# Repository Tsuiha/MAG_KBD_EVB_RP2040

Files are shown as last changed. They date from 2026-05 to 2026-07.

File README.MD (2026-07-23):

# vial-qmkとRP2040で作る磁気キーボード

rp2040とmuxを使用して作る磁気キーボード用の設計情報です。
簡単なguideにpdfも入れています。

firmwareはvial-qmkのforkです。
[firmware](https://github.com/Tsuiha/vial-qmk/tree/he/keyboards/0_he_rp2040/mag_kbd_evb)

[software](https://tsuiha.github.io/qmagk_configlator/)

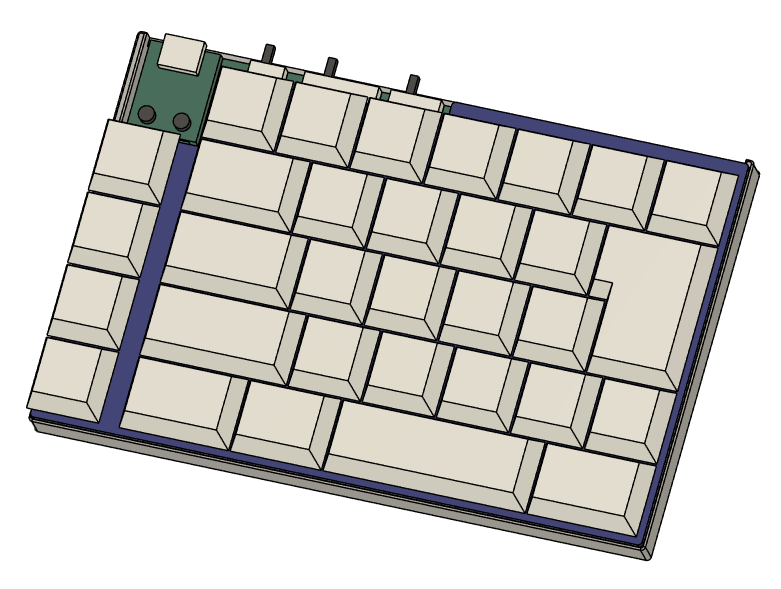
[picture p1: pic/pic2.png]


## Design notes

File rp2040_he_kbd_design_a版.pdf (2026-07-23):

## ○はじめに

## ○事前準備

## ○必要な設定

## ○ホールセンサの接続モード

## ○磁気設定ソフトウェア

quantum\keyboard.c, main.cファイルを一部変更する必要があります。 普段使用しているvial-qmkをコピペしkeyboard.cファイルを置き換えたvial-qmk-heプロジェクトを作成し ます。
https://github.com/Tsuiha/vial-qmk/blob/he/
通常のvial-qmkよりも応答性が改善しております。

config.hファイルを編集し使用するピンやパラメータの設定を行います。 kleで作成したvial用jsonファイルからレイアウト関連ファイルをツールを使い生成します。 その他vial-qmkと同様に設定します。

config.hで3パターンの接続モードから一つを有効化します。 #define DIRECT_ADC_MODE
#define DIRECT_MUX_MODE

#define CHAIN_MUX_MODE

磁気関連のラピトリやsocd, キャリブレーションは専用のソフトウェアを使用し行うことができます。 https://tsuiha.github.io/qmagk_configlator/
キーマップの設定はvialを使用します。

RP2040ZEROで作る！磁気キーボードを元にしたvial-qmkとrp2040を使用して磁気キーボードを設計 参考資料になります。

qmk firmwareでは何も知らない状態からkeyboard.jsonとキーマップを作成して基板を配線するだけ で自作キーボードを設計することができます。

磁気キーボードも同様に設計を行うことができます。そのための設定箇所等についてのメモになりま す。

qmkでの自作キーボード設計、ホールセンサやマルチプレクサの動作や制御について軽く調べておくこ とでスムーズに設計することができます。

またqmk firmwareとrp2040で製作する以上、ポーリングレートがスキャンレートでデッドゾーンの精度 が低遅延なハイスペック機は作れません。

# VIAL-QMKとRP2040で作る！ 磁気キーボード設計

### ○DIRECT_ADC_MODE

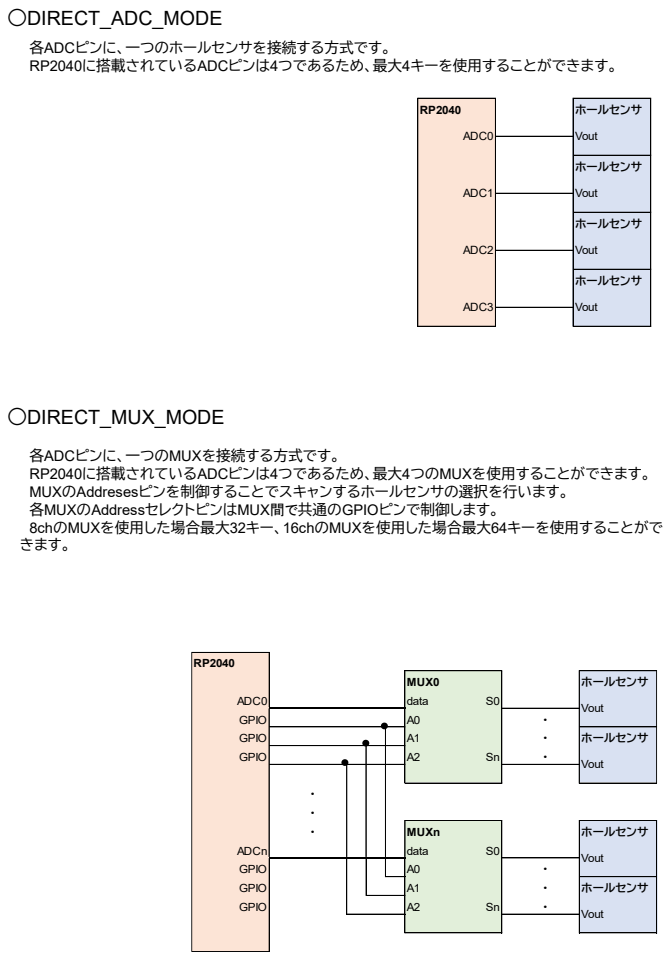
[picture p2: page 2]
○DIRECT_MUX_MODE; 各ADCピンに、一つのMUXを接続する方式です。 RP2040に搭載されているADCピンは4つであるため、最大4つのMUXを使用することができます。 MUXのAddresesピンを制御することでスキャンするホールセンサの選択を行います。 各MUXのAddressセレクトピンはMUX間で共通のGPIOピンで制御します。 8chのMUXを使用した場合最大32キー、16chのMUXを使用した場合最大64キーを使用することがで きます。; 各ADCピンに、一つのホールセンサを接続する方式です。 RP2040に搭載されているADCピンは4つであるため、最大4キーを使用することができます。; ホールセンサ; ADC3; Vout; ADC0; ADC1; ADC2; MUX0; data; GPIO; MUXn; ADCn

### ○CHAIN_MUX_MODE

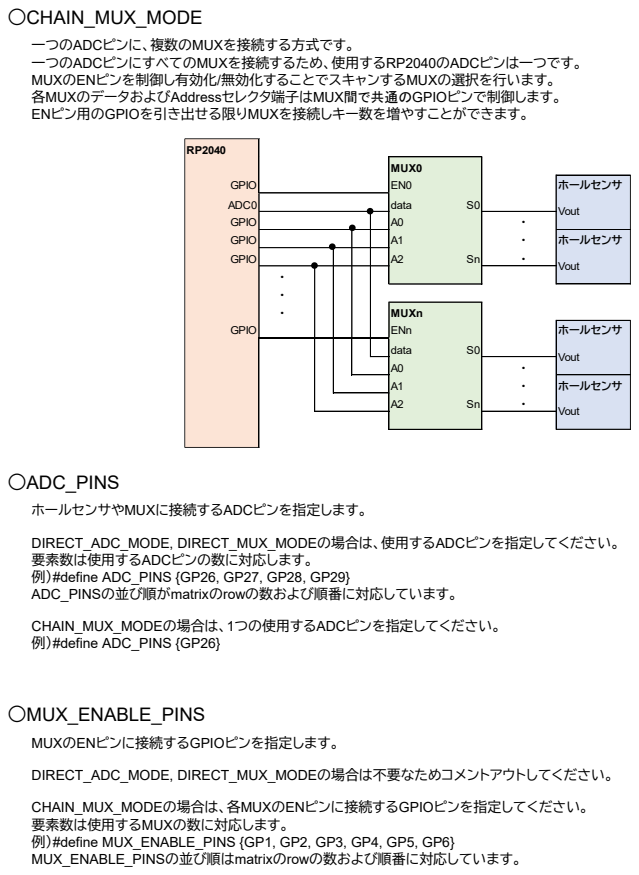
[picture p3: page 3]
○ADC_PINS; ○MUX_ENABLE_PINS; MUXのENピンに接続するGPIOピンを指定します。; DIRECT_ADC_MODE, DIRECT_MUX_MODEの場合は不要なためコメントアウトしてください。; CHAIN_MUX_MODEの場合は、各MUXのENピンに接続するGPIOピンを指定してください。 要素数は使用するMUXの数に対応します。 例）#define MUX_ENABLE_PINS {GP1, GP2, GP3, GP4, GP5, GP6} MUX_ENABLE_PINSの並び順はmatrixのrowの数および順番に対応しています。; ホールセンサやMUXに接続するADCピンを指定します。; DIRECT_ADC_MODE, DIRECT_MUX_MODEの場合は、使用するADCピンを指定してください。 要素数は使用するADCピンの数に対応します。 例）#define ADC_PINS {GP26, GP27, GP28, GP29} ADC_PINSの並び順がmatrixのrowの数および順番に対応しています。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

### ○MUX_CH_ORDER

### ○MUX_SELECT_PINS

### ○MATRIX_ROWS

### ○MATRIX_COLS

DIRECT_ADC_MODE, DIRECT_MUX_MODEの場合、使用するADCピンの数と対応します。 CHAIN_MUX_MODEの場合は、使用するMUXの数と対応します。

DIRECT_ADC_MODEの場合、1になります。
DIRECT_MUX_MODE, CHAIN_MUX_MODEの場合は、使用するMUXのch数と対応します。

MUXのAddressセレクトピンに接続するGPIOピンを指定します。

DIRECT_ADC_MODEの場合は不要なためコメントアウトしてください。

DIRECT_MUX_MODE, CHAIN_MUX_MODEの場合は、セレクタピンに接続するGPIOピンを指定して ください。
要素数は使用するMUXのch数の2進数の桁数に対応します。
例）#define MUX_SELECT_PINS {GP1, GP2, GP3}
MUX_SELECT_PINSの並び順は左側がLSB, 右側がMSBに対応しています。

MUXの使用するchを指定します。

DIRECT_ADC_MODEの場合は不要なためコメントアウトしてください。

DIRECT_MUX_MODE, CHAIN_MUX_MODEの場合は、スキャンする必要のあるchを指定してくださ い。
どのMUXでも使用していないchがある場合、指定せず省いてください。
例）#define MUX_CH_ORDER {0, 1, 2, 3, 4, 5, 6, 7} MUX_CH_ORDERの並び順はmatrixのcolの数および順番に対応しています。

## ○PCBキャリブレーション設定

## ○スイッチキャリブレーション設定

## ○感度オフセット設定

本機では入力感度の調整にsp5tスライドスイッチを使用しており、切り替えることで5段階のキー感度を 利用することができます。
使用するスライドスイッチの各接点に接続するGPIOピンを指定してください。
例）#define SENSI_OFFSET_PINS {GP1, GP2, GP3, GP4, GP5} 要素数は使用するスライドスイッチの接点数に対応します。

各感度ステージでの感度オフセット量をum単位で設定することができます。 例）#define DEF_OFFSET_PONT {0, 50, 100, 200, 500}

＊設定ソフトをリリースしたため、ソフトウェア上で感度ステージを切り替えられるようになりました。 また、vialのユーザーマクロにもsensi offset切り替えキーを作成しております。 スライドスイッチのハードウェア実装はoptionになります。

本機ではキー入力とスイッチキャリブレーションの動作モード切り替えにspdtスライドスイッチを使用し ています。

スライドスイッチのスイッチキャリブレーションモード側接点に接続するGPIOピンを指定してください。 例）#define SW_CAL_PIN GP1

＊設定ソフトをリリースしたため、ソフトウェア上でキャリブレーションを実行できるようになりました。 スライドスイッチのハードウェア実装はoptionになります。

本機ではPCBキャリブレーション用のスイッチとしてタクトスイッチを使用しており、押した状態で起動 するとPCBキャリブレーションが実施されるようになっています。 PCBキャリブレーション用のスイッチに接続するGPIOピンを指定してください。
例）#define PCB_CAL_PIN GP1

ホールセンサの磁束密度ゼロ点出力を取得するものです。 使用するホールセンサに合わせた初期値を設定してしまい、PCBキャリブレーション機能をオミットして も使用に問題はありません
（例えばDRV5055であれば2048を、DRV5056であれば744を固定値として設定してしまう） 例）#define DEF_REF_ADC_VAL 2048

＊設定ソフトをリリースしたため、ソフトウェア上でキャリブレーションを実行できるようになりました。 スライドスイッチのハードウェア実装はoptionになります。

### ○SOCD設定

## ○ゲーミングキー設定

## ○スイッチストローク

### ○KLE to LAYOUT

使用するスイッチのストロークを指定してください。
#define DEF_STROKE 3400

本機の使用ではスイッチストロークの異なるスイッチを使用した場合、感度のみ変化します。 設定ストローク ： 設定感度 ＝ 実ストローク ： 実感度

＊設定ソフトをリリースしたため、ソフトウェア上で設定いただけます。

vial.jsonを生成する際にkleで作成したjsonファイルをもとに作成していると思います。 付属のpywアプリを使用し、kleで作成したjsonファイルから関連layoutファイルをすべて生成することがで きます。
https://github.com/Tsuiha/MAG_KBD_EVB_RP2040/blob/main/pyw/kle_to_layout/kle_multi_layout_to ol.pyw

使用するにはpythonのインストールとpathを通す作業が必要です。

＊設定ソフトをリリースしたため、任意のキーのラピトリ, SOCDを設定いただけます。

本機ではWASDキーに付与するSOCD機能を2つのモードから選択することができます。 SOCDモードの切り替えにsp2tスライドスイッチを使用しています。各端子に接続するGPIOピンを指定 する必要があります。
例）#define SOCD_PINS {GP6, GP7}
SOCD_PINSの並び順は左からOFF, ONに対応しています。 SOCD切り替えにスライドスイッチを使用しない場合はコメントアウトしてください。

＊設定ソフトをリリースしたため、ソフトウェア上でオンオフを切り替えられるようになりました。 また、vialのユーザーマクロにもsocd mode切り替えキーを作成しております。 スライドスイッチのハードウェア実装は になります。

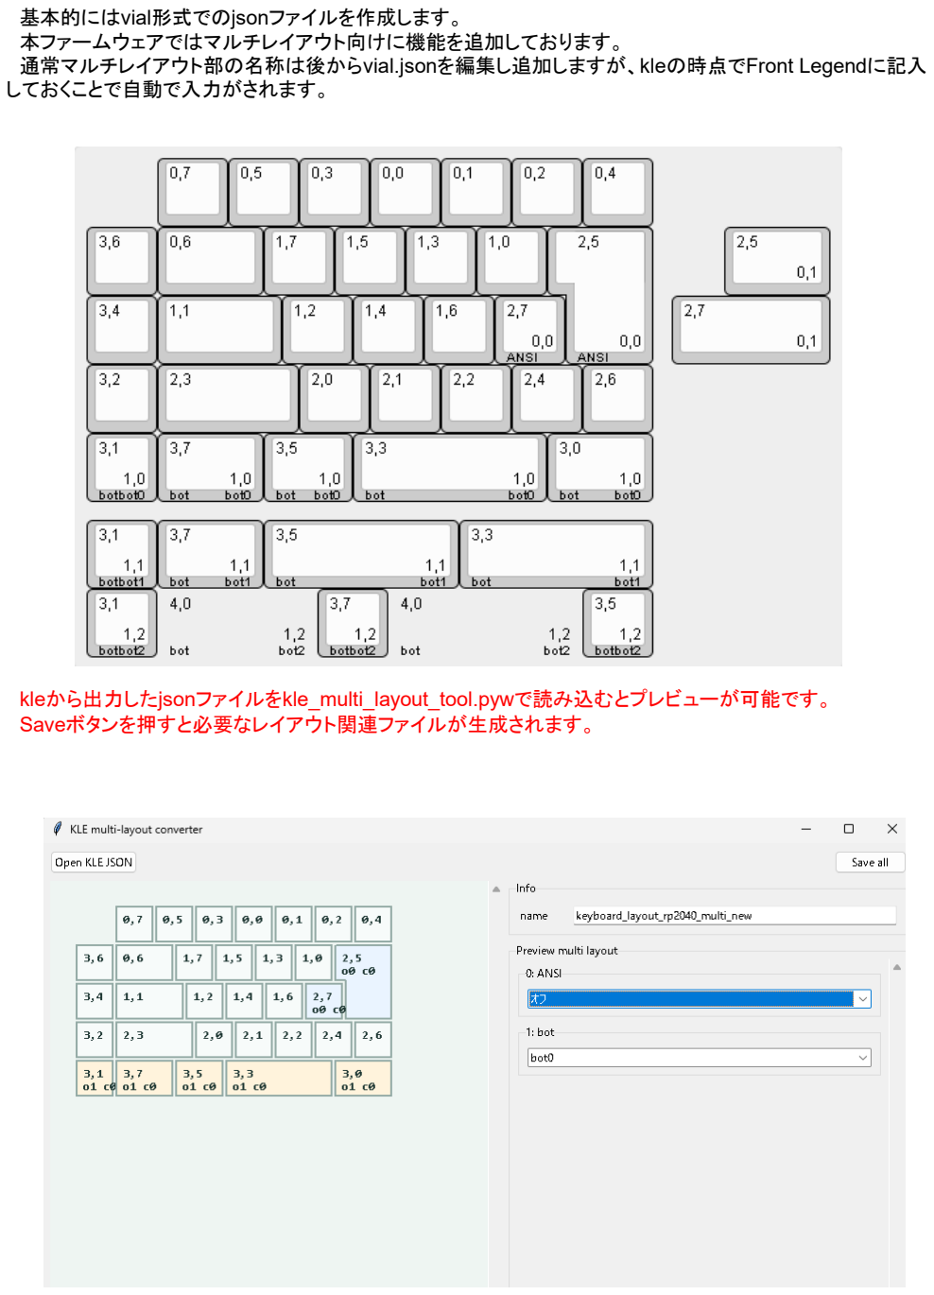
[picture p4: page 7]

kleから出力したjsonファイルをkle_multi_layout_tool.pywで読み込むとプレビューが可能です。 Saveボタンを押すと必要なレイアウト関連ファイルが生成されます。

基本的にはvial形式でのjsonファイルを作成します。 本ファームウェアではマルチレイアウト向けに機能を追加しております。 通常マルチレイアウト部の名称は後からvial.jsonを編集し追加しますが、kleの時点でFront Legendに記入 しておくことで自動で入力がされます。

## ○部品選び

生成されたファイルについて
・key_layout.c
カスタムマトリクスで使用します。keyboard名フォルダ直下に格納してください。

・keyboard_layout.json
keyboard.jsonのlayout部分のみ生成されていますので、keyboard.json内にコピペしてください。

・keymap.c
keymap.cのひな型になります。キーコードは未記入です。

・vial.json
vial.jsonです。

本機はKS-20互換スイッチとDRV5055のようなスイッチを押すとホールセンサの出力電圧が上昇する組 み合わせに対応しています。
電子部品に関してはデータシートがしっかりしているベンダーの製品がいいと思います。

・ホールセンサ
DRV5055シリーズ・・・消費電力が比較的小さい
1mm, 1.2mm pcbの場合DRV5055A3
1.6mm pcbの場合DRV5055A2
MT910Xシリーズ・・・ちょっと安い
1mm, 1.2mm pcbの場合MT9102
1.6mm pcbの場合MT9105
1.2mm pcbかつ最近増えている高磁束スイッチとやらを使用しない場合MT9103 候補は他にもありますが、入手性を考えるとこのあたりがおすすめです。やや高価ですが私はDRV5055 しか使わないと思います。

・MUX
厳密な話をすると変わるのでしょうが大した差はないため、まともそうで入手性の良いものを選択すれ ばよいと思います。
私は特に理由はないですがTMUX1308を使用しています。

・磁気スイッチ
一般的であるためKS-20互換と呼ばれているものを使用します。 平均的な磁気スイッチの軸ブレによる磁束密度変動量をストロークの変動量に換算すると大体0.05mm 程度となります。酷いものだと換算0.1mm程度ブレますし、優秀なものでも換算0.02mm程度はブレるも のです。
トップアウト状態でキーキャップをなでたり、ボトムアウト状態でグリグリしたりすることでそれだけ検出 ストロークがブレるということです。
そのため軸ブレの小さなスイッチを使用することが精度の面では望ましく、新しめの製品の方が基本的 にはよいです。
ショートストロークが好みの場合、ZENAIMスイッチをKS-20互換スイッチ向けと同じ基板で使用すること ができます。プレートは別途設計が必要です。

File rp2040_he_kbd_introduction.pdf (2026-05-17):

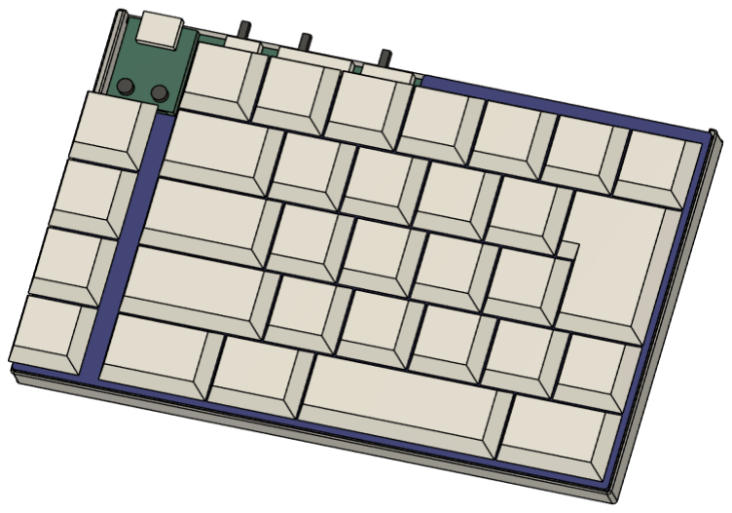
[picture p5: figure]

- 32キーレイアウトの自作磁気キーボード
- MXタイプのKS-20互換磁気スイッチに対応
- カスタムや新規設計が容易なQMK-Firmware
- Vial に対応したキーマッピング設定
- オンボードで完結する磁気関連設定
- ラピッドトリガー, SOCD機能
- WASD ▶ 直感的な操作を重視した高感度設定

他キー ▶ 意図しない誤入力を避けた低感度設定

- シーンに合わせて切り替え可能な5段階入力感度
- プロファイル不要のスイッチキャリブレーション機能

## RP2040ZEROで作る！磁気キーボード 取扱説明書

内容物・組み立てに必要な部品

- 内容物
- 必要物

・ 所謂KS-20互換スイッチの使用が想定されていますが、

各社製品仕様が異なるため使用可否は実際にご確認ください。

・ プレート, スタビライザーを交換することでZENAIMスイッチも使用可能です。

- キーレイアウト

・ キーマッピングはVialを使用して変更することができます。

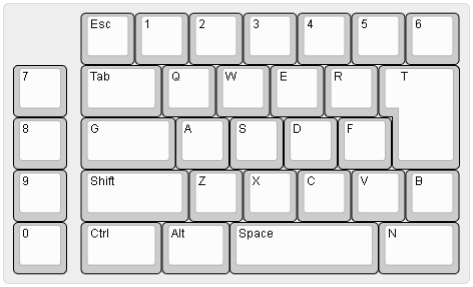
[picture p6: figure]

(keyboard-layout-editor.com)

実装基板(1mm pcb + rp2040zero) スイッチプレート(FR4 1.6mm)
トレイケース
3.5mm M2スペーサ x 6pcs
3mm M2ネジ x 6pcs
4mm M2ネジ x 6pcs
プレートマウントスタビライザー x 3pcs

キーキャップ x 32pcs
キースイッチ x 32pcs

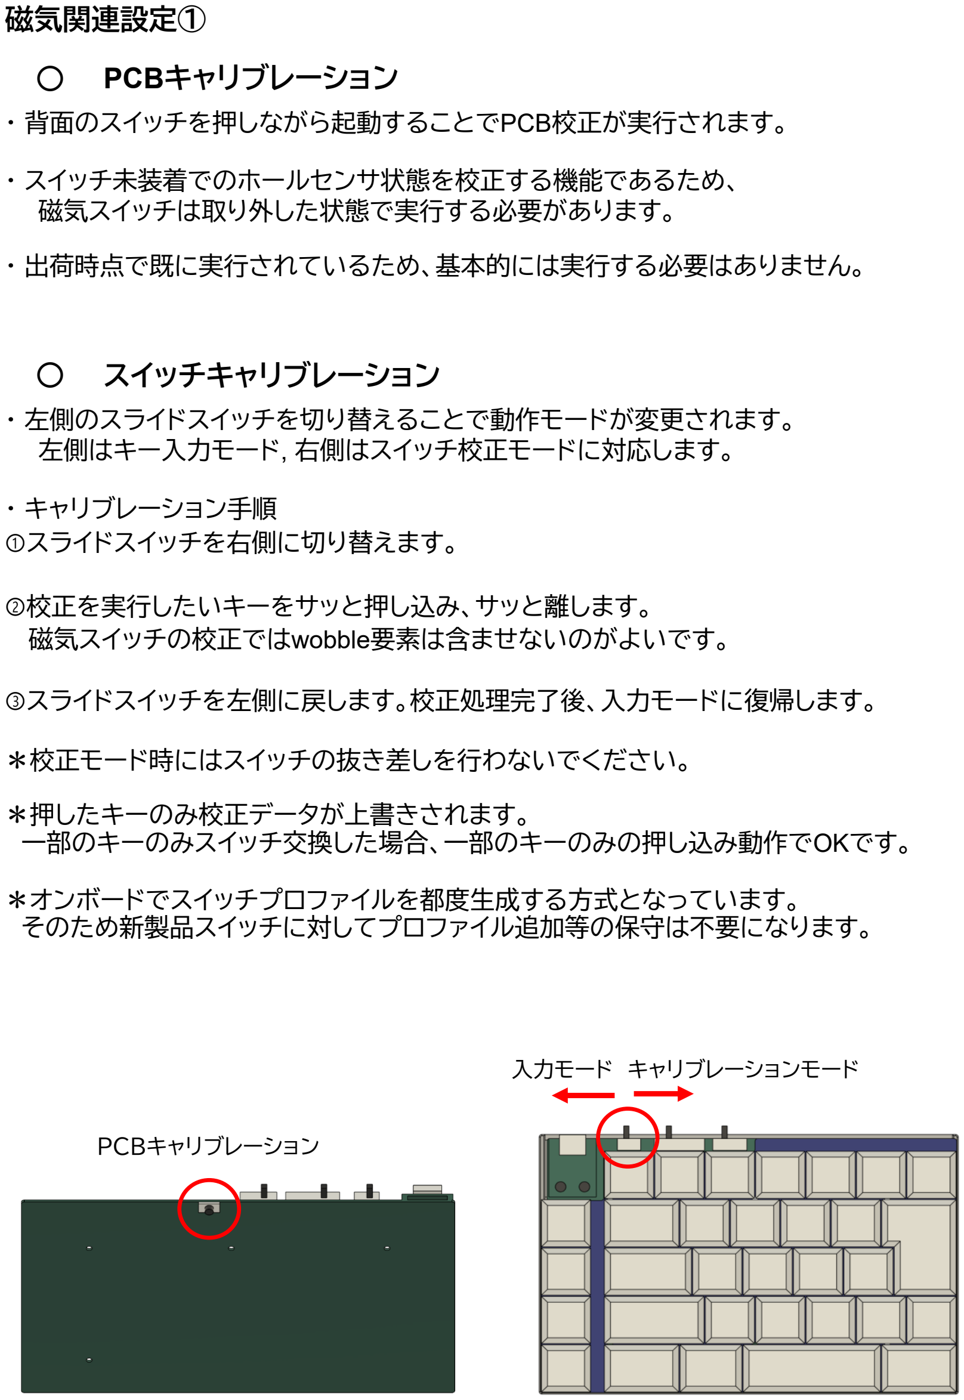
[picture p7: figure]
磁気関連設定①; ○ PCBキャリブレーション; ○ スイッチキャリブレーション; (keyboard-layout-editor.com); ・ 左側のスライドスイッチを切り替えることで動作モードが変更されます。 左側はキー入力モード, 右側はスイッチ校正モードに対応します。; ・ キャリブレーション手順 ①スライドスイッチを右側に切り替えます。; ②校正を実行したいキーをサッと押し込み、サッと離します。 磁気スイッチの校正ではwobble要素は含ませないのがよいです。; ③スライドスイッチを左側に戻します。校正処理完了後、入力モードに復帰します。; ＊校正モード時にはスイッチの抜き差しを行わないでください。; ＊押したキーのみ校正データが上書きされます。 一部のキーのみスイッチ交換した場合、一部のキーのみの押し込み動作でOKです。; ＊オンボードでスイッチプロファイルを都度生成する方式となっています。 そのため新製品スイッチに対してプロファイル追加等の保守は不要になります。; ・ 背面のスイッチを押しながら起動することでPCB校正が実行されます。; ・ スイッチ未装着でのホールセンサ状態を校正する機能であるため、 磁気スイッチは取り外した状態で実行する必要があります。; ・ 出荷時点で既に実行されているため、基本的には実行する必要はありません。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

磁気関連設定②

- ラピッドトリガー
- 入力感度オフセット
- SOCD

・ 右側のスライドスイッチを切り替えることでSOCDモードを変更することができます。 左側からOFF, HYBRID, FORCED モードとなっています。

OFF　・・・　SOCD機能無効
HYBRID　・・・　キャンセル対象キーが底打ち状態の場合キャンセルしません。 切り返し補助と同時押しストッピングを両立します。
FORCED　・・・　反対方向の移動キーをキャンセルします。

＊キャンセルのみのシンプルな機能となっています。再入力等の処理は行いません。

・ ラピッドトリガーの基本感度は固定になります。

Actuation Point　・・・　0.1mm（WASD） Actuation Point　・・・　0.4mm（Others） Actuation Trigger　・・・　0.05mm Reset Point　・・・　0.1mm
Reset Trigger　・・・　0.05mm

・ 中央のスライドスイッチを切り替えることで入力感度を調整することができます。 左に動かすと高感度に、右に動かすと低感度に設定が変更されます。 入力感度は 「基本感度+オフセット値」 で決定されます。

stage0　・・・　+0mm
stage1　・・・　+0.05mm
stage2　・・・　+0.1mm
stage3　・・・　+0.2mm
stage4　・・・　+0.5mm

入力感度オフセット SOCDモード

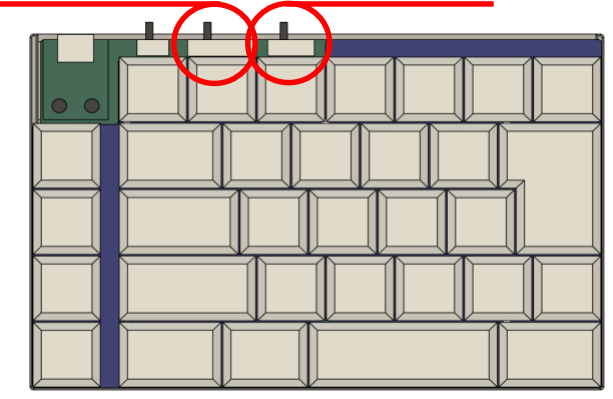
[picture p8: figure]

セットアップ

キーボードの状態確認（console）

初回起動時のセットアップ方法
・スイッチを嵌める。
・入力の暴発を抑えるため、入力感度オフセットを最大（最右）にしておく。 ・PCに接続する。
・スイッチキャリブレーションを実施する。

QMK MSYSをインストールしqmk consoleコマンドを打つと、キーボードの状態を確認す ることができます。それだけなのでconsoleの活用は必須ではありません。

consoleに接続した状態で本機をPCに接続すると、起動時のキャリブレーション状態が表 示されます。

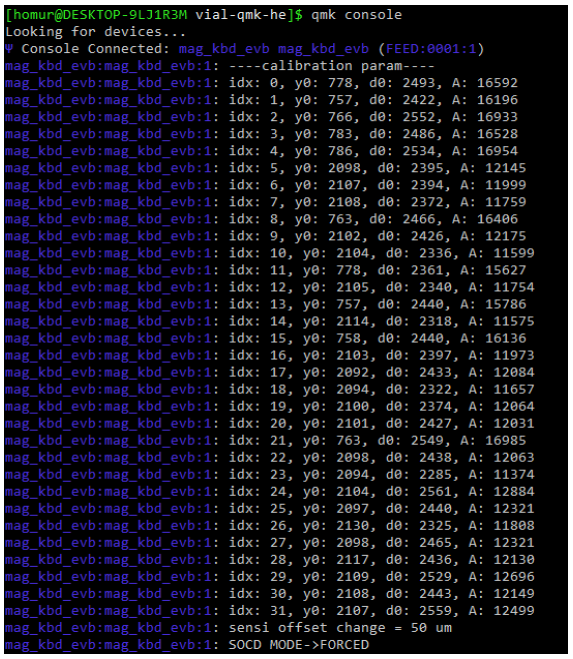
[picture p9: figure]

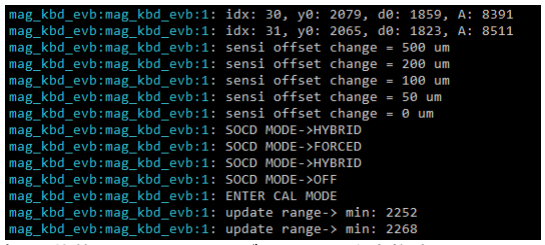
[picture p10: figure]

consoleに接続した状態でスイッチキャリブレーションを実施すると、キャリブレーションの 状況と結果を確認することができます。

使用していて明らかに動作がおかしい, 入力精度が悪化した, スイッチキャリブレーション を実施しても改善されない, といった場合、何らかの要因で保存された校正情報がクリアさ れている可能性があります。

校正情報が存在しない初期状態では、あらかじめ設定された固定値が使用されます。 初期化されてしまっているかどうかは、consoleから構成情報を確認するとすべて同一の 値になっていることで判別できます。

該当する場合は、PCBキャリブレーションおよびスイッチキャリブレーションを実施してくだ さい。

consoleに接続した状態でスライドスイッチを操作すると、現在の状態を表示します。

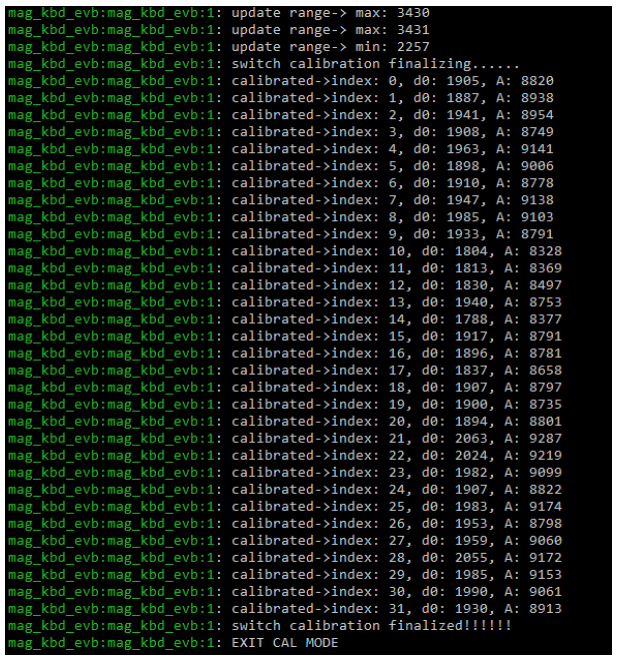
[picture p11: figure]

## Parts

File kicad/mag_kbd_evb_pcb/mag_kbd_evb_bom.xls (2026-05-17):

C1-36 | 0.1uF, 0603(1608m)
C37-38 | 1uF, 0603(1608m), no use
FB1 | BLM18PG121SN1D, 0603(1608m)
SW1 | spst, SMD,5.2x5.2mm
SW2 | spdt, slide switch, SK12D07VG5
SW3 | sp3t, slide switch, SK13D07VG5
SW4 | sp5t, slide switch, SK15D01G5
U1-32 | DRV5055A3(for 1mm pcb)
U33-36 | TMUX1308QDYYRQ1
U37 | RP2040ZERO
U38 | 3.3VLDO, TLV733

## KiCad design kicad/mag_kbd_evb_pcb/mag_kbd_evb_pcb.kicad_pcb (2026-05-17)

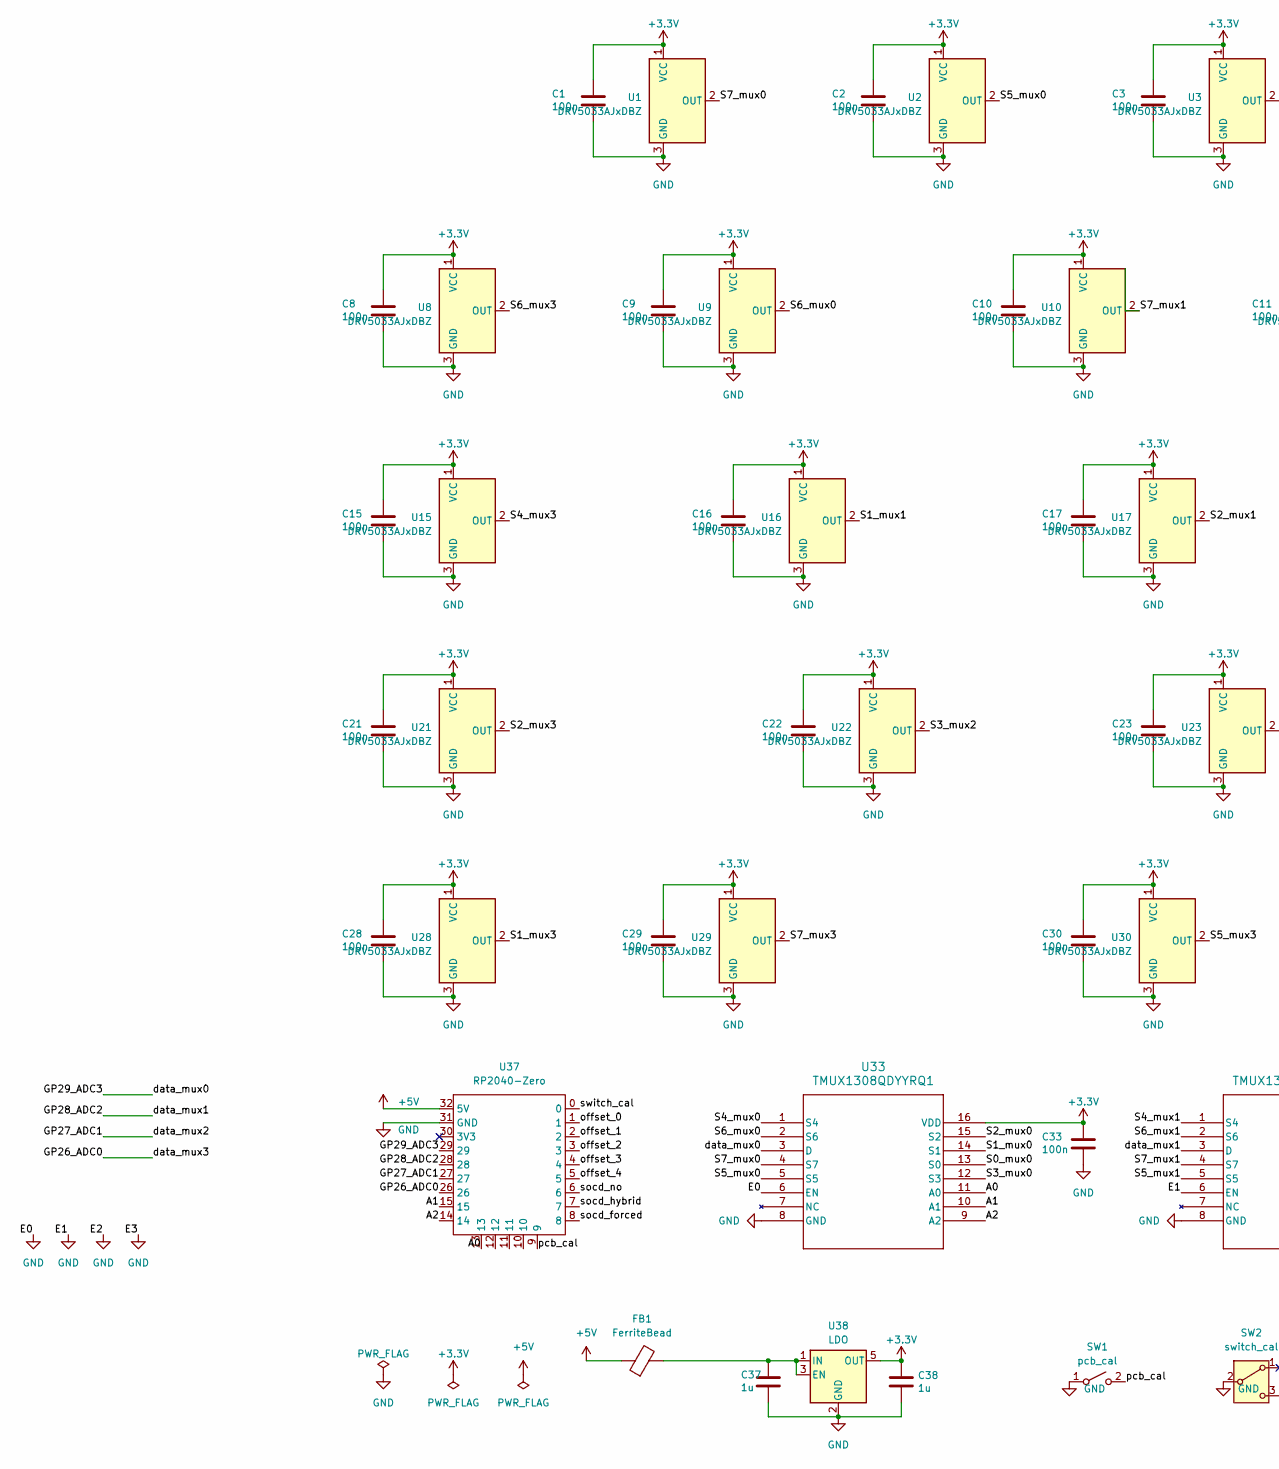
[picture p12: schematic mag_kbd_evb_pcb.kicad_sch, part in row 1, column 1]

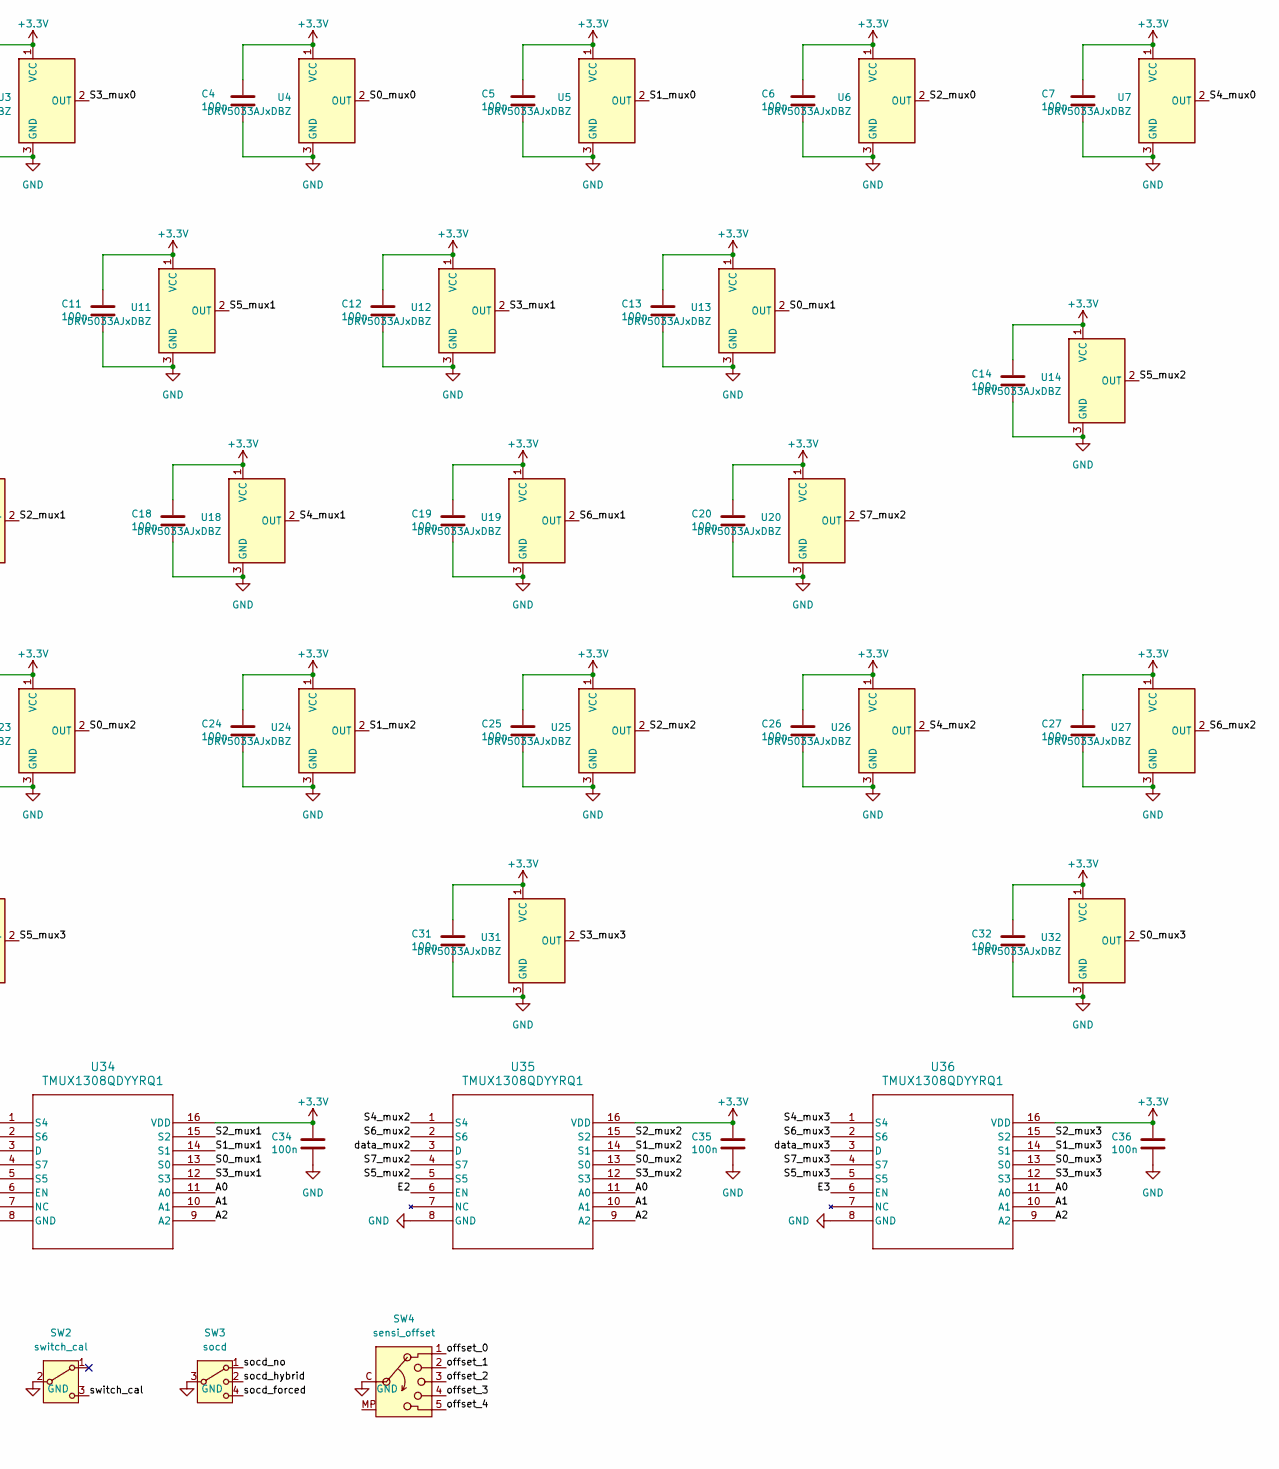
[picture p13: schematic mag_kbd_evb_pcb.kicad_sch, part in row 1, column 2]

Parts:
C1, C2, C3, C4, C5, C6, C7, C8, C9, C10, C11, C12, C13, C14, C15, C16, C17, C18, C19, C20, C21, C22, C23, C24, C25, C26, C27, C28, C29, C30, C31, C32, C33, C34, C35, C36: 100n; C_0603_1608Metric
C37, C38: 1u; C_0603_1608Metric
FB1: FerriteBead; C_0603_1608Metric
SW1: pcb_cal; SW_SPST_SKQG_WithStem
SW2: switch_cal; SHOUHAN_SK12D
SW3: socd; SHOUHAN_SK13D
SW4: sensi_offset; SHOUHAN_SK15D
U1, U2, U3, U4, U5, U6, U7, U8, U9, U10, U11, U12, U13, U14, U15, U16, U17, U18, U19, U20, U21, U22, U23, U24, U25, U26, U27, U28, U29, U30, U31, U32: DRV5033AJxDBZ; hallsensor_hall
U33, U34, U35, U36: TMUX1308QDYYRQ1; Texas_DYY0016A_TSOT-23-16_4.2x2.0mm_P0.5mm
U37: RP2040-Zero
U38: LDO; SOT-23-5

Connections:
+3.3V: C1.1, C2.1, C3.1, C4.1, C5.1, C6.1, C7.1, C8.1, C9.1, C10.1, C11.1, C12.1, C13.1, C14.1, C15.1, C16.1, C17.1, C18.1, C19.1, C20.1, C21.1, C22.1, C23.1, C24.1, C25.1, C26.1, C27.1, C28.1, C29.1, C30.1, C31.1, C32.1, C33.1, C34.1, C35.1, C36.1, C38.1, U1.1 (VCC), U2.1 (VCC), U3.1 (VCC), U4.1 (VCC), U5.1 (VCC), U6.1 (VCC), U7.1 (VCC), U8.1 (VCC), U9.1 (VCC), U10.1 (VCC), U11.1 (VCC), U12.1 (VCC), U13.1 (VCC), U14.1 (VCC), U15.1 (VCC), U16.1 (VCC), U17.1 (VCC), U18.1 (VCC), U19.1 (VCC), U20.1 (VCC), U21.1 (VCC), U22.1 (VCC), U23.1 (VCC), U24.1 (VCC), U25.1 (VCC), U26.1 (VCC), U27.1 (VCC), U28.1 (VCC), U29.1 (VCC), U30.1 (VCC), U31.1 (VCC), U32.1 (VCC), U33.16 (VDD), U34.16 (VDD), U35.16 (VDD), U36.16 (VDD), U38.5 (OUT)
+5V: FB1.1, U37.32 (5V)
/A0: U33.11 (A0), U34.11 (A0), U35.11 (A0), U36.11 (A0), U37.13
/A1: U33.10 (A1), U34.10 (A1), U35.10 (A1), U36.10 (A1), U37.15
/A2: U33.9 (A2), U34.9 (A2), U35.9 (A2), U36.9 (A2), U37.14
/GP26_ADC0: U36.3 (D), U37.26
/GP27_ADC1: U35.3 (D), U37.27
/GP28_ADC2: U34.3 (D), U37.28
/GP29_ADC3: U33.3 (D), U37.29
/S0_mux0: U4.2 (OUT), U33.13 (S0)
/S0_mux1: U13.2 (OUT), U34.13 (S0)
/S0_mux2: U23.2 (OUT), U35.13 (S0)
/S0_mux3: U32.2 (OUT), U36.13 (S0)
/S1_mux0: U5.2 (OUT), U33.14 (S1)
/S1_mux1: U16.2 (OUT), U34.14 (S1)
/S1_mux2: U24.2 (OUT), U35.14 (S1)
/S1_mux3: U28.2 (OUT), U36.14 (S1)
/S2_mux0: U6.2 (OUT), U33.15 (S2)
/S2_mux1: U17.2 (OUT), U34.15 (S2)
/S2_mux2: U25.2 (OUT), U35.15 (S2)
/S2_mux3: U21.2 (OUT), U36.15 (S2)
/S3_mux0: U3.2 (OUT), U33.12 (S3)
/S3_mux1: U12.2 (OUT), U34.12 (S3)
/S3_mux2: U22.2 (OUT), U35.12 (S3)
/S3_mux3: U31.2 (OUT), U36.12 (S3)
/S4_mux0: U7.2 (OUT), U33.1 (S4)
/S4_mux1: U18.2 (OUT), U34.1 (S4)
/S4_mux2: U26.2 (OUT), U35.1 (S4)
/S4_mux3: U15.2 (OUT), U36.1 (S4)
/S5_mux0: U2.2 (OUT), U33.5 (S5)
/S5_mux1: U11.2 (OUT), U34.5 (S5)
/S5_mux2: U14.2 (OUT), U35.5 (S5)
/S5_mux3: U30.2 (OUT), U36.5 (S5)
/S6_mux0: U9.2 (OUT), U33.2 (S6)
/S6_mux1: U19.2 (OUT), U34.2 (S6)
/S6_mux2: U27.2 (OUT), U35.2 (S6)
/S6_mux3: U8.2 (OUT), U36.2 (S6)
/S7_mux0: U1.2 (OUT), U33.4 (S7)
/S7_mux1: U10.2 (OUT), U34.4 (S7)
/S7_mux2: U20.2 (OUT), U35.4 (S7)
/S7_mux3: U29.2 (OUT), U36.4 (S7)
/offset_0: SW4.1, U37.1
/offset_1: SW4.2, U37.2
/offset_2: SW4.3, U37.3
/offset_3: SW4.4, U37.4
/offset_4: SW4.5, U37.5
/pcb_cal: SW1.2 (B), U37.9
/socd_forced: SW3.4, U37.8
/socd_hybrid: SW3.2, U37.7
/socd_no: SW3.1, U37.6
/switch_cal: SW2.3 (C), U37.0
GND: C1.2, C2.2, C3.2, C4.2, C5.2, C6.2, C7.2, C8.2, C9.2, C10.2, C11.2, C12.2, C13.2, C14.2, C15.2, C16.2, C17.2, C18.2, C19.2, C20.2, C21.2, C22.2, C23.2, C24.2, C25.2, C26.2, C27.2, C28.2, C29.2, C30.2, C31.2, C32.2, C33.2, C34.2, C35.2, C36.2, C37.2, C38.2, SW1.1 (A), SW2.2 (B), SW3.3, SW4.C (Common), U1.3 (GND), U2.3 (GND), U3.3 (GND), U4.3 (GND), U5.3 (GND), U6.3 (GND), U7.3 (GND), U8.3 (GND), U9.3 (GND), U10.3 (GND), U11.3 (GND), U12.3 (GND), U13.3 (GND), U14.3 (GND), U15.3 (GND), U16.3 (GND), U17.3 (GND), U18.3 (GND), U19.3 (GND), U20.3 (GND), U21.3 (GND), U22.3 (GND), U23.3 (GND), U24.3 (GND), U25.3 (GND), U26.3 (GND), U27.3 (GND), U28.3 (GND), U29.3 (GND), U30.3 (GND), U31.3 (GND), U32.3 (GND), U33.6 (EN), U33.8 (GND), U34.6 (EN), U34.8 (GND), U35.6 (EN), U35.8 (GND), U36.6 (EN), U36.8 (GND), U37.31 (GND), U38.2 (GND)
unnamed: C37.1, FB1.2, U38.1 (IN), U38.3 (EN)

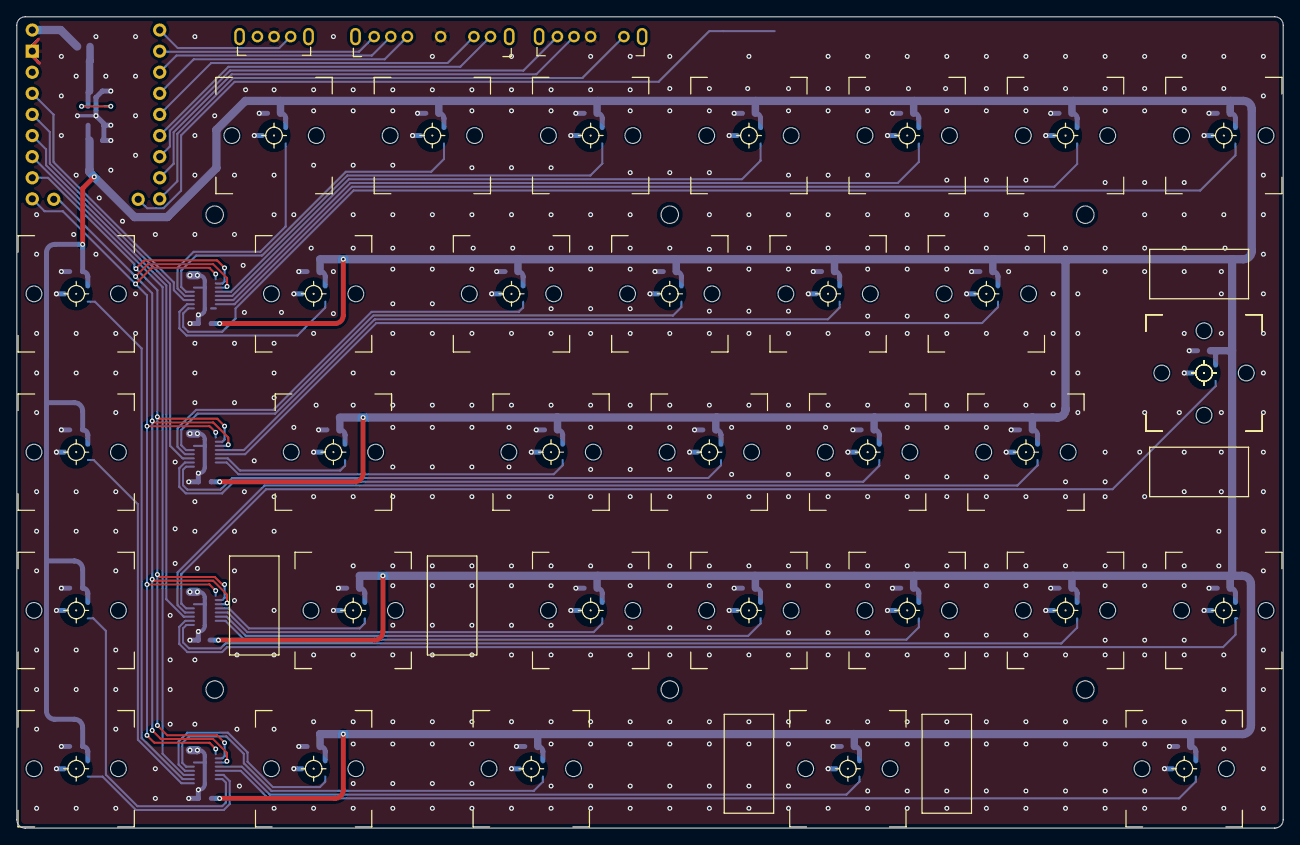
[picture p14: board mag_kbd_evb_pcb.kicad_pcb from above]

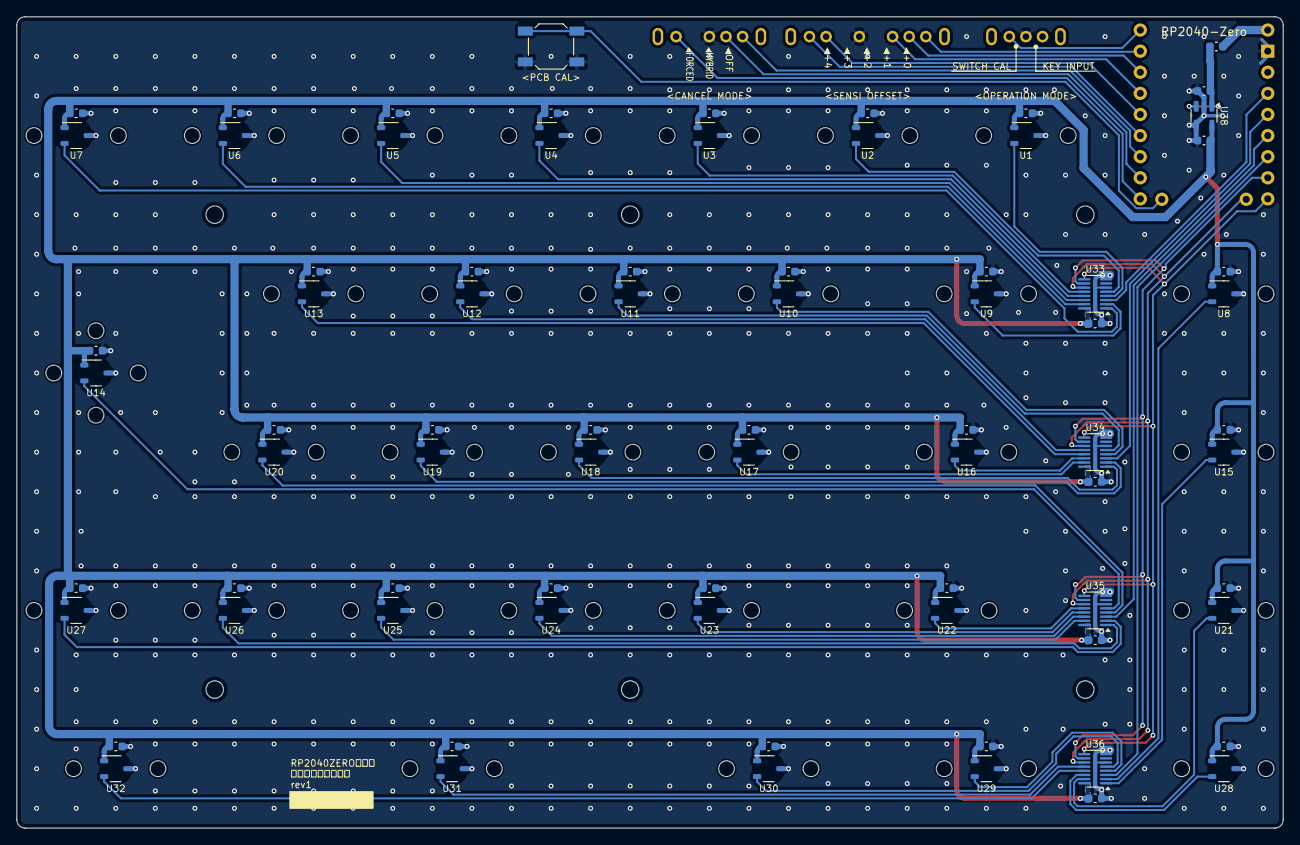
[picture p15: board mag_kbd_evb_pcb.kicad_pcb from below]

Board: 2 copper layers, 152.4 x 97.6 mm, 114 parts (77 on the bottom side), 53 nets.

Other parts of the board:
SW6, SW6#2, SW6#3, SW6#4, SW6#5, SW6#6, SW6#7, SW6#8, SW6#10, SW6#11, SW6#12, SW6#14, SW6#15, SW6#16, SW6#17, SW6#18, SW6#19, SW6#21, SW6#22, SW6#25, SW6#26, SW6#27, SW6#29, SW6#32, SW6#33: SW_PUSH; Magnetic_switch_hole_c
SW6#9: SW_PUSH; Magnetic_switch_hole_c_2
SW6#13: SW_PUSH; Magnetic_switch_hole_c_ISO
SW6#20, SW6#24, SW6#28: SW_PUSH; Magnetic_switch_hole_c_15
SW6#23: SW_PUSH; Magnetic_switch_hole_c_125
SW6#30: SW_PUSH; Magnetic_switch_hole_c_175
SW6#31: SW_PUSH; Magnetic_switch_hole_c_275
